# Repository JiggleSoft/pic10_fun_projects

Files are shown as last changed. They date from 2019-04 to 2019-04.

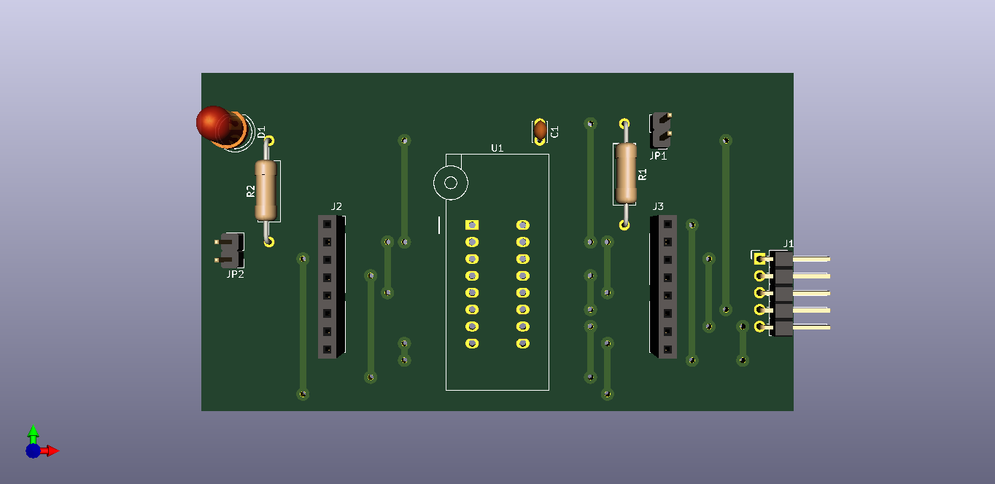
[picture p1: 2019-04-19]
general/pic10_zif_program_board/eng/kicad/pic10_zif_programming_board/pic10_zif_programming_board_3D_Front.png

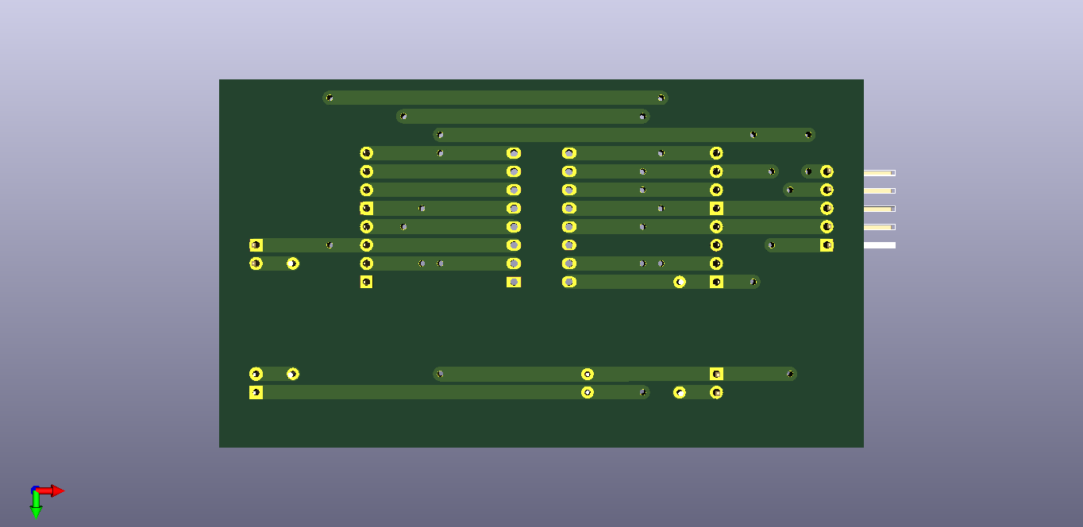
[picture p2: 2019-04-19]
general/pic10_zif_program_board/eng/kicad/pic10_zif_programming_board/pic10_zif_programming_board_3D_Back.png

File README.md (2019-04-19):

# JiggleSoft

Click [here](http://www.jigglesoft.co.uk) to visit the JiggleSoft web site

# Microchip PIC10 Fun Projects

Home on GitHub (https://github.com/JiggleSoft/pic10_fun_projects)

## Contact Details

Justin Lane (pic10funprojects@jigglesoft.co.uk)

## Why?

  * Why not?
  * It is fun to make cool stuff.
  * MCU is very cheap at approx. 50 pence each in small quantities.
  * Very limited resources (RAM,ROM,Stack,I/O):
    * Less to learn and remember.
      * Data Sheet is 88 pages for PIC10F200/202/204/206 ([Download](http://ww1.microchip.com/downloads/en/DeviceDoc/40001239F.pdf)).
    * Small ROM allows practical development in assembly language.
	  * Programs are limited in size so assembly language is practical.
	  * Get an appreciation of what is going on inside the CPU.
	* Learn to squeeze and make best use of every available resource.
	  * This is missing from the software these days where 3GHz multi-core CPUs with vast RAM and storage can be thrown at problems.
    * Simpler projects, so are quick to build.
  * Available in PDIP so no SMT soldering required.
  * Circuits can be wired on breadboards and made in classrooms.
  * PCB layouts are Stripboard friendly so no custom PCBs are necessary.

## Completed Projects

  * General 
    * Microchip PIC10 (and PIC12) Programming ZIF Socket Board.
      * Allows out-of-circuit programming of PIC10 and PIC12 MCU's via a PICKit 2,3,4, or any compatible programmer ([Buy](https://new.microchipdirect.com/product/search/all/pg164140)).

## Work-In-Progress

  * General 
    * Microchip PIC10 General Purpose Development Board.
      * General purpose board that can be built in various flavours to support wiring up projects on a bench with jumper leads.
  * Visible Light Emitting Diode (LED)
   * Flashing LED Test Program.
   * Morse Code Beacon.
   * Mood Light (RGB).
   * Matrix 8x8 with MAX7219 driver.
  * Joke
    * IR LED Annoying Covert Possessed Remote Control.

## For Consideration

  * Visible Light Emitting Diode (LED)
    * Die.
    * Decision Maker
    * Night Light (variation on Mood Light).
  * Jokes
    * IR LED Remote Control Jammer.
    * Annoying Sounds (PIC and Piezzo Sounder).
  * Games
    * Wild West Quick Draw Game
    * Reaction Game
    * Memory Game (Repeat Sequence)
    * Skill Electric Wire
    * LED 8x8 Game/Toy Hand Held
  * Cool
    * Morse Decoder
    * Video Demo
    * SoDAR
    * Organ
    * Fart Detector
  * To Classify
    * Line Follow
    * Environmentatl_Alarm_Humidity_Temp
    * Movement_Detector_Alarm

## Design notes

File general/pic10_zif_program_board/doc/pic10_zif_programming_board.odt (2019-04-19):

Microchip PIC10 Simple Fun Projects

Out-of-Circuit ZIF Programming Board

Author: Justin Lane (pic10funprojects@jigglesoft.co.uk)

Date: 2019-04-06 12:00:00

Version: 3.0.1

# Introduction

Project to provide an method of programming out of circuit, the Microchip PIC10 and PIC12 8-pin MCUs in the DIP package, by insertion into a ZIF socket, and programmed by a PICKit 2, 3, and 4 or compatible programmer device. Also contains a switchable -MCLR weak pull-up resistor and a switchable test LED on one of the general purpose I/O lines.

# Block Diagram

ZIF SOCKET

Test LED

Microchip PIC10/ PIC12 8-pin DIP ICSP 5-pin header Microchip PICKit 4 or compatible Programmer

-MCLR Pull-up

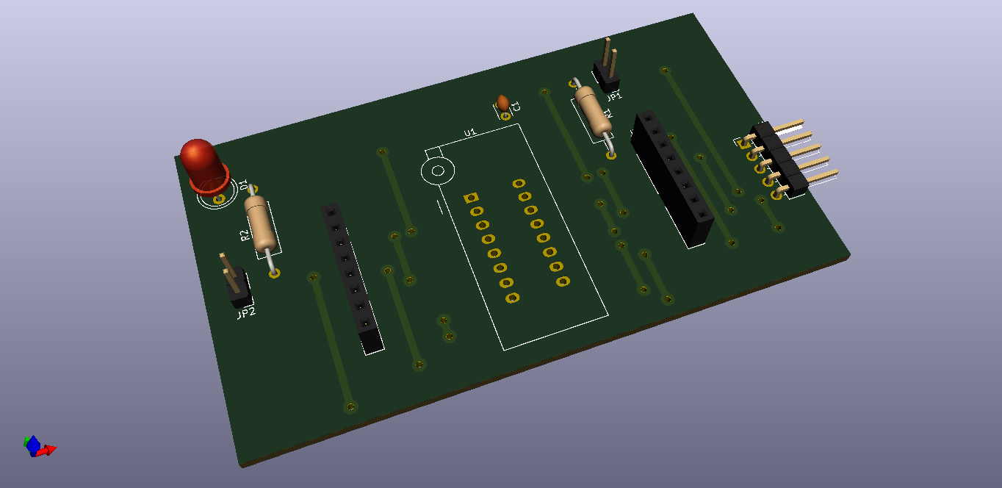
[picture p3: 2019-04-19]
general/pic10_zif_program_board/eng/kicad/pic10_zif_programming_board/pic10_zif_programming_board_3D_Nice.png

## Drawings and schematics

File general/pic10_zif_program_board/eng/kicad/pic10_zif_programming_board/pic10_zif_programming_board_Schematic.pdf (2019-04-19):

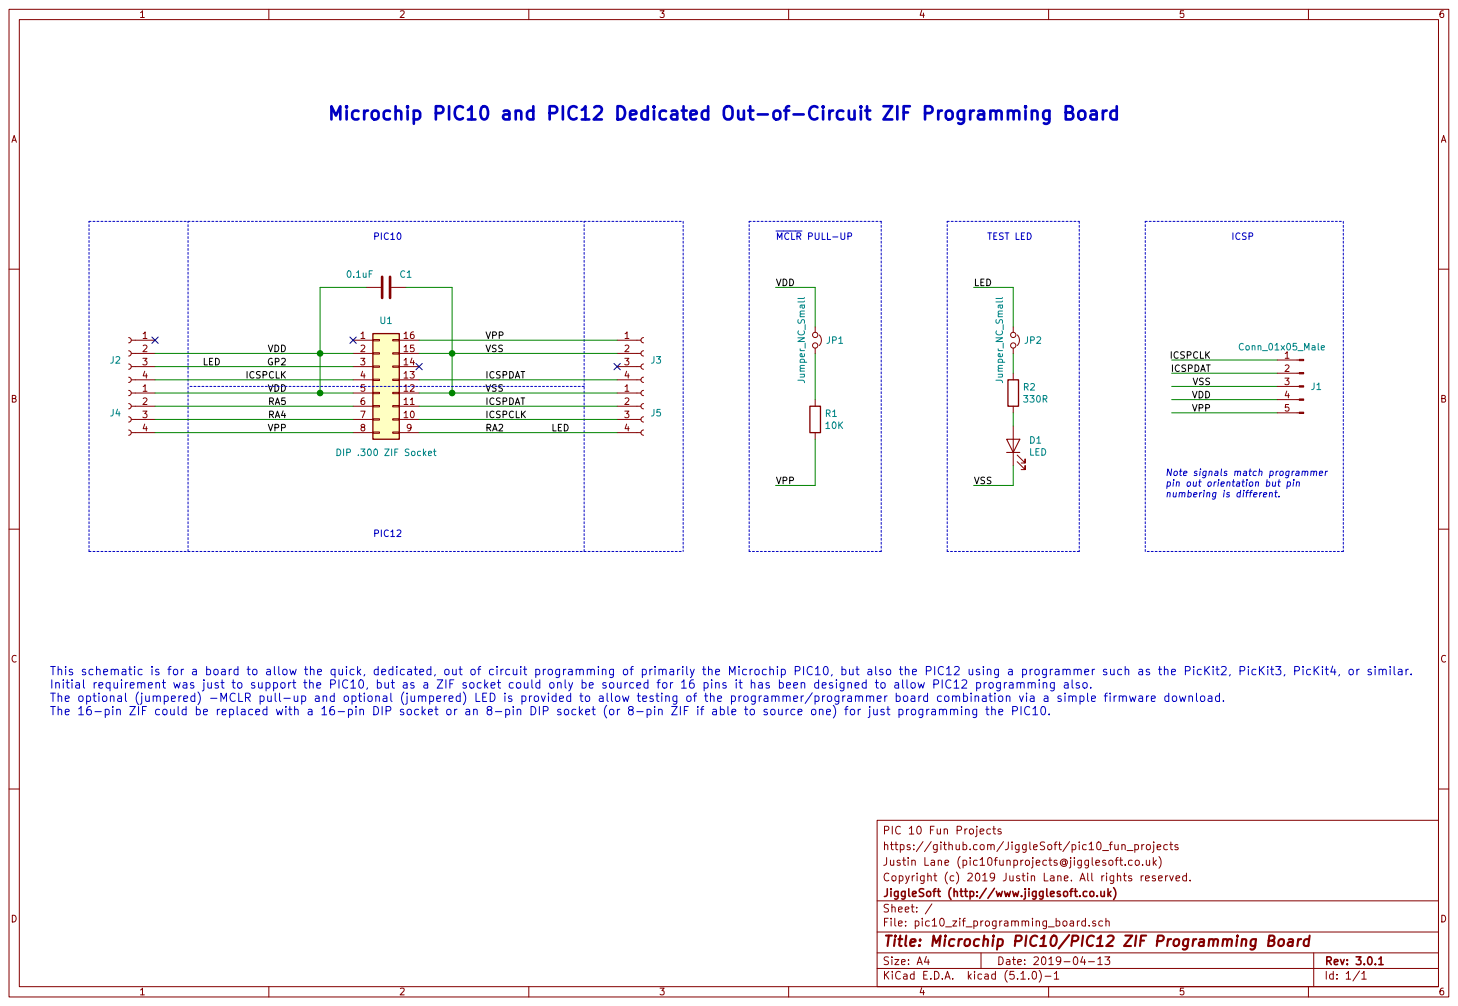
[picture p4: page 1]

Microchip PIC10 and PIC12 Dedicated Out-of-Circuit ZIF Programming Board

J1 Conn_01x05_Male Note signals match programmer
ICSPCLK
ICSPDAT VSS

pin out orientation but pin
numbering is different.

This schematic is for a board to allow the quick, dedicated, out of circuit programming of primarily the Microchip PIC10, but also the PIC12 using a programmer such as the PicKit2, PicKit3, PicKit4, or similar.
Initial requirement was just to support the PIC10, but as a ZIF socket could only be sourced for 16 pins it has been designed to allow PIC12 programming also.
The optional (jumpered) -MCLR pull-up and optional (jumpered) LED is provided to allow testing of the programmer/programmer board combination via a simple firmware download.
The 16-pin ZIF could be replaced with a 16-pin DIP socket or an 8-pin DIP socket (or 8-pin ZIF if able to source one) for just programming the PIC10.

PIC 10 Fun Projects
https://github.com/JiggleSoft/pic10_fun_projects
Justin Lane (pic10funprojects@jigglesoft.co.uk)
Copyright (c) 2019 Justin Lane. All rights reserved.
File: pic10_zif_programming_board.sch Sheet: / JiggleSoft (http://www.jigglesoft.co.uk)

Id: 1/1 Title: Microchip PIC10/PIC12 ZIF Programming Board

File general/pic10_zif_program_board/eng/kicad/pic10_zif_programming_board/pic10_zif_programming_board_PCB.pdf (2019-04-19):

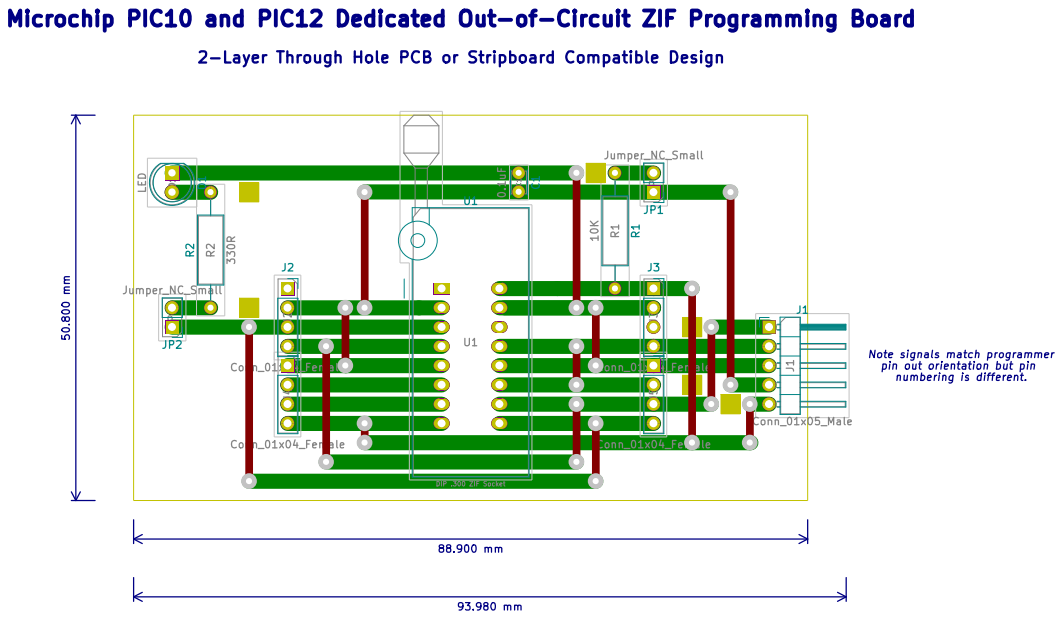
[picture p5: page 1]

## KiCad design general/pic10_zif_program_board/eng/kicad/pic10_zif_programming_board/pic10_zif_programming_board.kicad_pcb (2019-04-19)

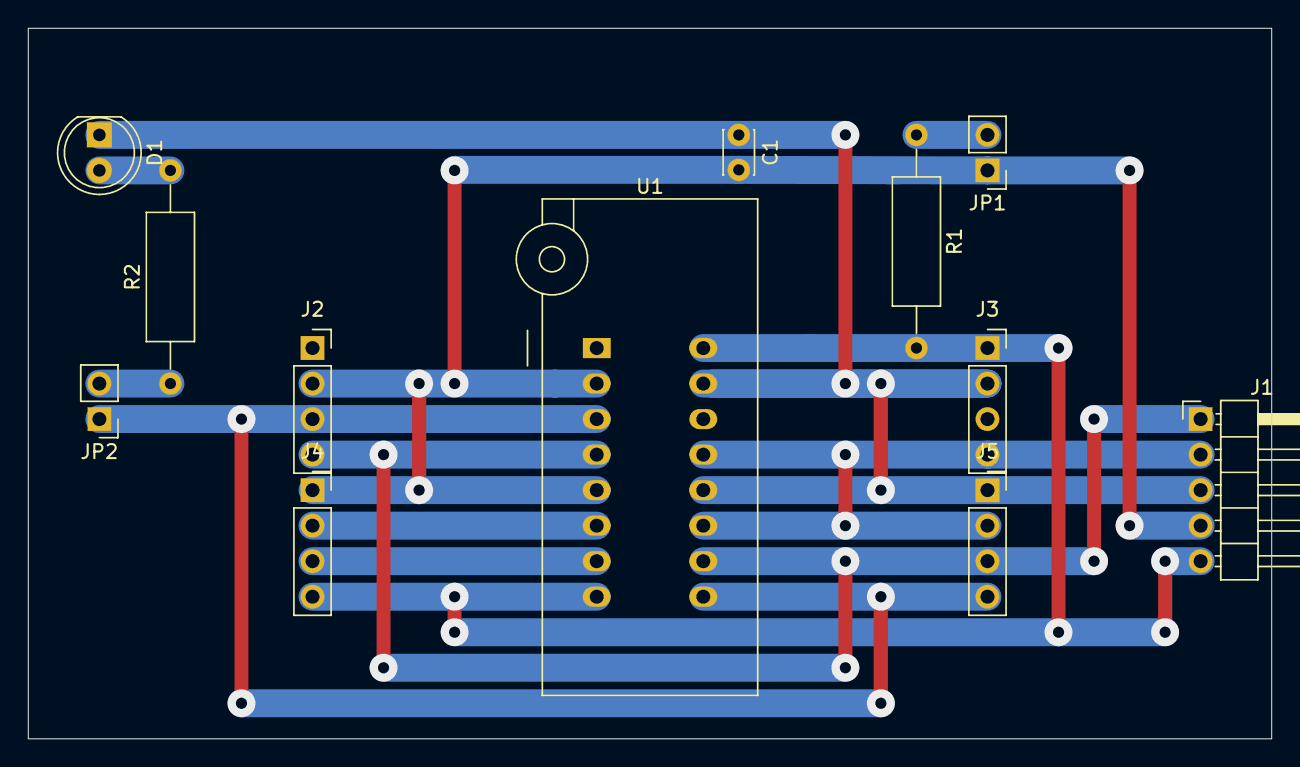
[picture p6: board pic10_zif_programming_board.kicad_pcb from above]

Board: 2 copper layers, 88.9 x 50.8 mm, 12 parts (0 on the bottom side), 11 nets.

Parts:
C1: 0.1uF; C_Disc_D3.0mm_W2.0mm_P2.50mm
D1: LED; LED_D5.0mm
J1: Conn_01x05_Male; PinHeader_1x05_P2.54mm_Horizontal
J2, J3, J4, J5: Conn_01x04_Female; PinSocket_1x04_P2.54mm_Vertical
JP1, JP2: Jumper_NC_Small; PinHeader_1x02_P2.54mm_Vertical
R1: 10K; R_Axial_DIN0309_L9.0mm_D3.2mm_P15.24mm_Horizontal
R2: 330R; R_Axial_DIN0309_L9.0mm_D3.2mm_P15.24mm_Horizontal
U1: DIP .300 ZIF Socket; DIP_Socket-16_W4.3_W5.08_W7.62_W10.16_W10.9_3M_216-3340-00-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

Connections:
/GP2: J2.3, J5.4, JP2.1, U1.3, U1.9
/ICSPCLK: J1.1, J2.4, J5.3, U1.4, U1.10
/ICSPDAT: J1.2, J3.4, J5.2, U1.11, U1.13
/RA4: J4.3, U1.7
/RA5: J4.2, U1.6
/VDD: C1.2, J1.4, J2.2, J4.1, JP1.1, U1.2, U1.5
/VPP: J1.5, J3.1, J4.4, R1.2, U1.8, U1.16
/VSS: C1.1, D1.1, J1.3, J3.2, J5.1, U1.12, U1.15
unnamed: D1.2, R2.2
unnamed: JP1.2, R1.1
unnamed: JP2.2, R2.1
